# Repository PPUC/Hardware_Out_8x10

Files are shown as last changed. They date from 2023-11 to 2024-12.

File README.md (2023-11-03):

# Lamp Matrix PCB for PPUC Project
This is the hardware for a LED lamp matrix card which was designed for the PPUC pinball project, but can be useful in other applications as well. The intentionally usecase is to connect an original equipped pinball playfield (including cable harness). Normally I'd prefer a serial WS2812 LED strip to do a DIY pinball but if all the LEDs and cables are in place already, it is useful to connect the lamp matrix directly (for LED use only, not for incandescent bulbs as power of the outputs is limited).
It is designed for being low cost and functional for experimental use.  
Not everything is tested nor does it fulfill EMC or any other specifications.  
Use at your own risk!
To make use of anything of this project a basic understanding of electronics and programming is necessary. Nothing of it is "plug and play". I'm surely not liable for any damage to assemblies, pinball machines or even persons.

## Picture of the Board
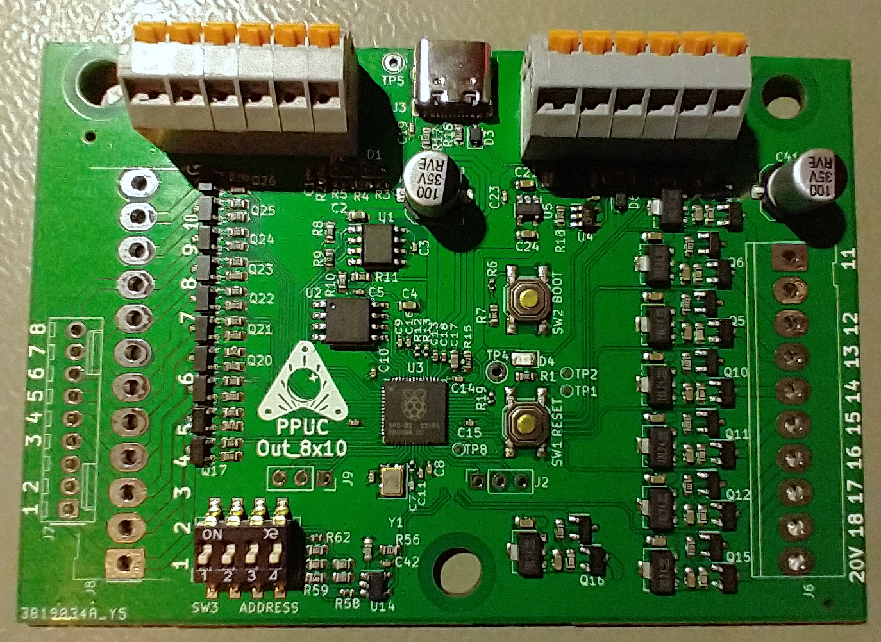
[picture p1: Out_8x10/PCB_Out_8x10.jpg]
PCB Pic


## Name
Out_8x10 as it has 18 outputs. 8 high side switches and 10 low side switches which can form a 8x10 matrix but could also be used as simple high side and low side outputs.  

## Power Supply
The IO card must be supplied by 5 V (+-0.5 V) for logic and nominal 20 V for outputs. As these outputs are open source and open drain, the 20 V supply can actually be 7 V up to 26 V. In the circuit diagram the voltage is called 20 V.

## Controller
A RP2040 is used for it's cost/performance ratio. It is the same controller that is used in the Raspberry Pi Pico.

## Communication Interfaces
* RS_485: main communication interface for controlling the outputs. Usually connected to a host interface like a PC or Raspberry Pi or similar.
* USB C: for programming, debug and flashing
* Serial Wire: alternative for programming, debug and flashing

## Switches (on board)
* Reset: hardware reset for controller (RP2040)
* Boot: if active, the board connects to a PC like an USB stick. Usually used for programming the code into the flash memory on the board.
* DIP-switches: usually used to select an address for RS485 (16 combinations)

## High Side Switch Outputs
There are 8 outputs featuring a high side switch, usually used for lamp coloums. The voltage is derived form 20 V power connection. Current and power is limited by a linear regulator (78L24) wich is actually not used for regulating the voltage but to protect the switch form overload in case of a short circuit. Each output can drive a constant current of 100 mA witch is normaly sufficiant for 10 LED lamps (e.g. 10 rows of LEDs). Short term peak current is about 300 mA. The 20 V supply can actually range from 7 V to 26 V (the lower limit is derived from UGS of the high side FET).

## Low Side Switch Outputs
There are 10 outputs featuring a low side switch, usually used for lamp rows. The outputs are open drain and drive currents up to 3 A with a load connected to a voltage of up to 30 V.

## Special Output
One special output is available for high speed signals. The voltage is 5 V, it is a push pull output that can drive a current up to 8 mA. It can be used to e.g. control a WS2812 LED strip.

## Connectors
There are pads for connectors that fit S.A.M. systems and also WPC systems. Be aware that J5 (WPC columns) is actually not in the PCB layout as it can be mounted on pins 1 to 9 of J6 (S.A.M. columns). The pinning is unfortunately vice versa so the connector of the original WPC cable harness has to be rotated by 180° (cables go to the inner side of PCB).

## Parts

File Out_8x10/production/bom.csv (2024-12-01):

Designator | Footprint | Quantity | Value | LCSC Part #
C1, C10, C11, C12, C14, C15, C16, C19, C20, C23, C3, C42, C5, C8, C9 | 0402 | 15 | 100n
C13, C18 | 0402 | 2 | 1u
C17, C2, C21, C24, C4 | 0603 | 5 | 10u
C22, C41 | CP_Elec_6.3x7.7 | 2 | 100µ 35V
C25, C26, C27, C28, C29, C30, C31, C32, C33, C34, C35, C36, C37, C38, C39, C40 | 0603 | 16 | 1u 50V
C6, C7 | 0402 | 2 | 27pF
D1, D2 | D_SOD-323 | 2 | SD15
D3, D7 | D_SOD-323 | 2 | 1A
D4 | 0805 | 1 | LED gn
D5 | D_SMA | 1 | SMAJ5.0
D6 | D_SOD-323 | 1 | SD05
J1, J4 | Terminal_Block_RTMPin | 2 | Conn_01x06
J3 | USB_C_Receptacle_XKB_U262-16XN-4BVC11 | 1 | USB_C_Receptacle_USB2.0
J6 | Molex_KK-396_5273-10A_1x10_P3.96mm_Vertical | 1 | Conn_01x10
J7 | Molex_KK-254_AE-6410-09A_1x09_P2.54mm_Vertical | 1 | Conn_01x09
J8 | Molex_KK-396_5273-12A_1x12_P3.96mm_Vertical | 1 | Conn_01x12
JP1 | PinHeader_1x02_P2.54mm_Vertical | 1 | Jumper_2_Open
Q1, Q13, Q14, Q2, Q3, Q7, Q8, Q9 | SOT-23 | 8 | 2N7002
Q10, Q11, Q12, Q15, Q16, Q4, Q5, Q6 | SOT-23 | 8 | AO3401A
Q17, Q18, Q19, Q20, Q21, Q22, Q23, Q24, Q25, Q26 | SOT-23 | 10 | AO3400A
R1, R10, R11, R18, R36, R37, R38, R39, R44, R45, R46, R47, R52, R53, R7, R8 | 0603 | 16 | 10k
R12, R13 | 0402 | 2 | 27
R14, R19, R58, R6, R62 | 0402 | 5 | 1k
R15, R2, R40, R41, R42, R43, R48, R49, R50, R51, R54, R55 | 0603 | 12 | 100R
R16, R17 | 0603 | 2 | 5k1
R20, R21, R22, R26, R27, R28, R32, R33, R57, R60, R61, R64 | 0603 | 12 | 2k
R23, R24, R25, R29, R30, R31, R34, R35 | 0603 | 8 | 3k3
R4 | 0603 | 1 | 120R
R56 | 0603 | 1 | 33k
R59 | 0603 | 1 | 5k
R63 | 0603 | 1 | 3k
R9 | 0603 | 1 | 0
SW1 | SW_SPST_SKQG_WithStem | 1 | Reset
SW2 | SW_SPST_SKQG_WithStem | 1 | Boot
SW3 | SW_DIP_SPSTx04_Slide_6.7x11.72mm_W8.61mm_P2.54mm_LowProfile | 1 | ADDRESS
TP1 | TestPoint_Pad_D1.0mm | 1 | TP_IO26
TP2 | TestPoint_Pad_D1.0mm | 1 | TP_IO27
U1 | SOIC-8_3.9x4.9mm_P1.27mm | 1 | ADM3483
U10, U11, U12, U13, U6, U7, U8, U9 | SOT-89-3 | 8 | L78L24_SOT89
U14 | SOT-23-5 | 1 | LMV321
U2 | SOIC-8_5.23x5.23mm_P1.27mm | 1 | W25Q128JVSIQ
U3 | QFN-56-1EP_7x7mm_P0.4mm_EP3.2x3.2mm | 1 | RP2040
U4 | SOT-23-5 | 1 | SN74AHCT1G125
U5 | SOT-23-5 | 1 | AP2112K-3.3
Y1 | Crystal_SMD_3225-4Pin_3.2x2.5mm | 1 | 12MHz,18pF

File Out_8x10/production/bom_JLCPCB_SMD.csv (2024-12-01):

Designator | Footprint | Quantity | Value | LCSC Part #
C1, C10, C11, C12, C14, C15, C16, C19, C20, C23, C3, C42, C5, C8, C9 | 0402 | 15 | 100n | C1525
C13, C18 | 0402 | 2 | 1u | C52923
C17, C2, C21, C24, C4 | 0603 | 5 | 10u | C19702
C22, C41 | CP_Elec_6.3x7.7 | 2 | 100µ 35V | C2836437
C25, C26, C27, C28, C29, C30, C31, C32, C33, C34, C35, C36, C37, C38, C39, C40 | 0603 | 16 | 1u 50V | C15849
C6, C7 | 0402 | 2 | 27pF | C1557
D1, D2 | D_SOD-323 | 2 | SD15 | C502529
D3, D7 | D_SOD-323 | 2 | 1A | C191023
D4 | 0805 | 1 | LED gn | C2297
D5 | D_SMA | 1 | SMAJ5.0 | C2925443
D6 | D_SOD-323 | 1 | SD05 | C2972756
J3 | USB_C_Receptacle_XKB_U262-16XN-4BVC11 | 1 | USB_C_Receptacle_USB2.0 | C709357
Q1, Q13, Q14, Q2, Q3, Q7, Q8, Q9 | SOT-23 | 8 | 2N7002 | C8545
Q10, Q11, Q12, Q15, Q16, Q4, Q5, Q6 | SOT-23 | 8 | AO3401A | C15127
Q17, Q18, Q19, Q20, Q21, Q22, Q23, Q24, Q25, Q26 | SOT-23 | 10 | AO3400A | C20917
R1, R10, R11, R18, R36, R37, R38, R39, R44, R45, R46, R47, R52, R53, R7, R8 | 0603 | 16 | 10k | C25804
R12, R13 | 0402 | 2 | 27 | C138021
R14, R19, R58, R6, R62 | 0402 | 5 | 1k | C11702
R15, R2, R40, R41, R42, R43, R48, R49, R50, R51, R54, R55 | 0603 | 12 | 100R | C22775
R16, R17 | 0603 | 2 | 5k1 | C23186
R20, R21, R22, R26, R27, R28, R32, R33, R57, R60, R61, R64 | 0603 | 12 | 2k | C22975
R23, R24, R25, R29, R30, R31, R34, R35 | 0603 | 8 | 3k3 | C22978
R4 | 0603 | 1 | 120R | C22787
R56 | 0603 | 1 | 33k | C4216
R59 | 0603 | 1 | 5k | C101077
R63 | 0603 | 1 | 3k | C4211
R9 | 0603 | 1 | 0 | C21189
SW1 | SW_SPST_SKQG_WithStem | 1 | Reset | C318884
SW2 | SW_SPST_SKQG_WithStem | 1 | Boot | C318884
SW3 | SW_DIP_SPSTx04_Slide_6.7x11.72mm_W8.61mm_P2.54mm_LowProfile | 1 | ADDRESS | C54950
U1 | SOIC-8_3.9x4.9mm_P1.27mm | 1 | ADM3483 | C609792
U10, U11, U12, U13, U6, U7, U8, U9 | SOT-89-3 | 8 | L78L24_SOT89 | C5309539
U14 | SOT-23-5 | 1 | LMV321 | C7972
U2 | SOIC-8_5.23x5.23mm_P1.27mm | 1 | W25Q128JVSIQ | C97521
U3 | QFN-56-1EP_7x7mm_P0.4mm_EP3.2x3.2mm | 1 | RP2040 | C2040
U4 | SOT-23-5 | 1 | SN74AHCT1G125 | C7484
U5 | SOT-23-5 | 1 | AP2112K-3.3 | C51118
Y1 | Crystal_SMD_3225-4Pin_3.2x2.5mm | 1 | 12MHz,18pF | C9002

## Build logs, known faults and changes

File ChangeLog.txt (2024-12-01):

2024-12-01  foenich

	Released Version 1.0.0
	Jumper for RS485 termination. Removed bias resistors.
	Prevented current from USB to 5V_IN.
	More terminals for A and B.
	
	* removed F1 (as +5V is no loger at a terminal)
	* inserted D7
	* changed J1, pin 4 from GND to A and pin 5 from GND to B
	* inserted JP1
	* removed R3 and R5

2023-10-22  foenich

	Released Version 0.2.0
	TP as RM2.54 terminal
	
	* changed 3 TPs to RM2.54 terminal
	* changed versioning to x.y.z (major.functional change.bugfix)

2023-10-20  foenich

	Released Version 00.20
	read DIP switch analog (SW compatible to IO_16_8_1)
	
	* added anlog circuit and changed wiring to uC

2023-10-08  foenich

	Released initial Version 0.10

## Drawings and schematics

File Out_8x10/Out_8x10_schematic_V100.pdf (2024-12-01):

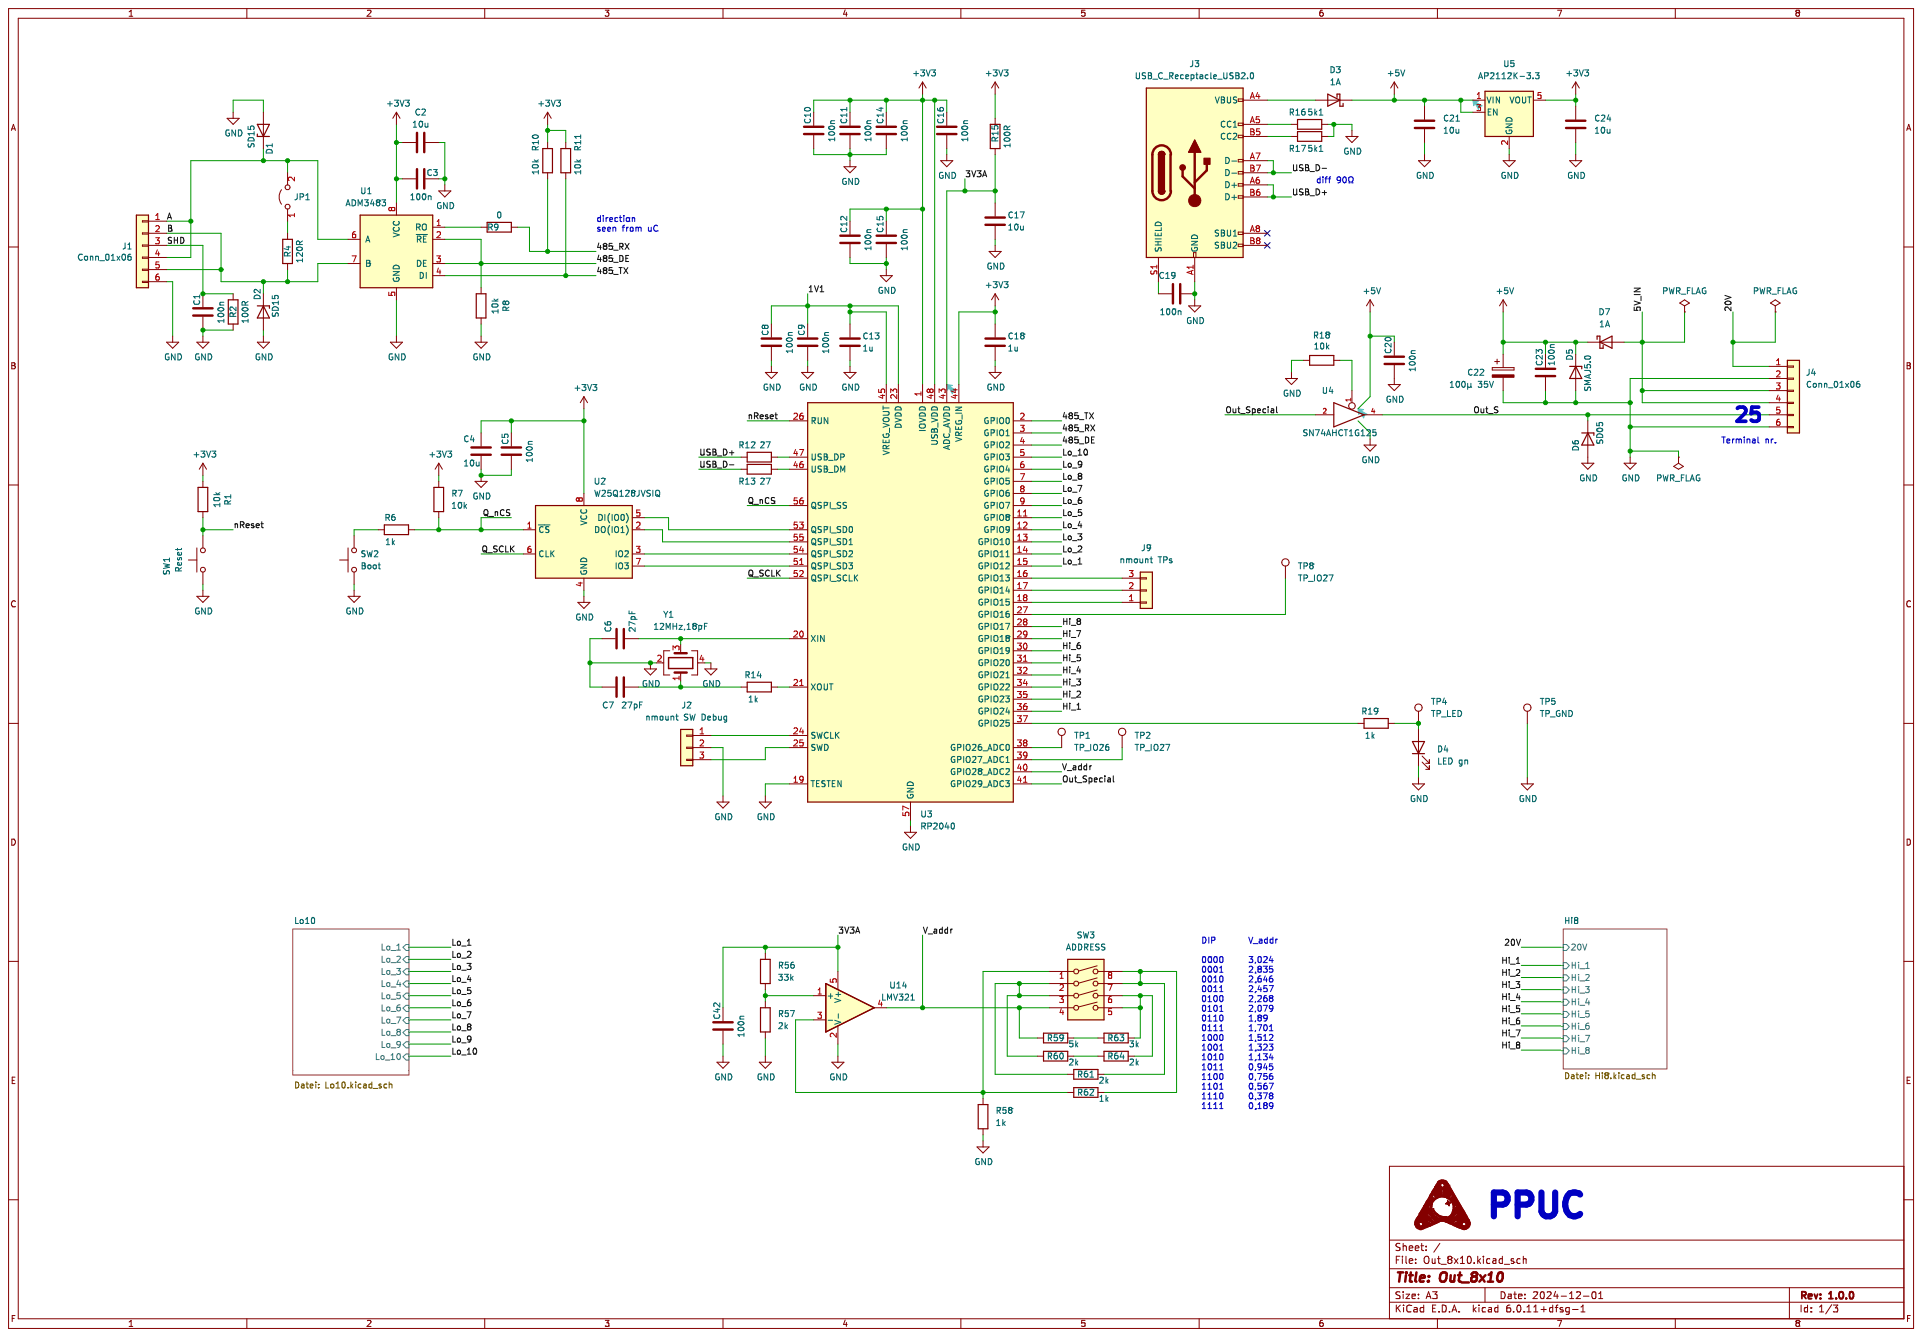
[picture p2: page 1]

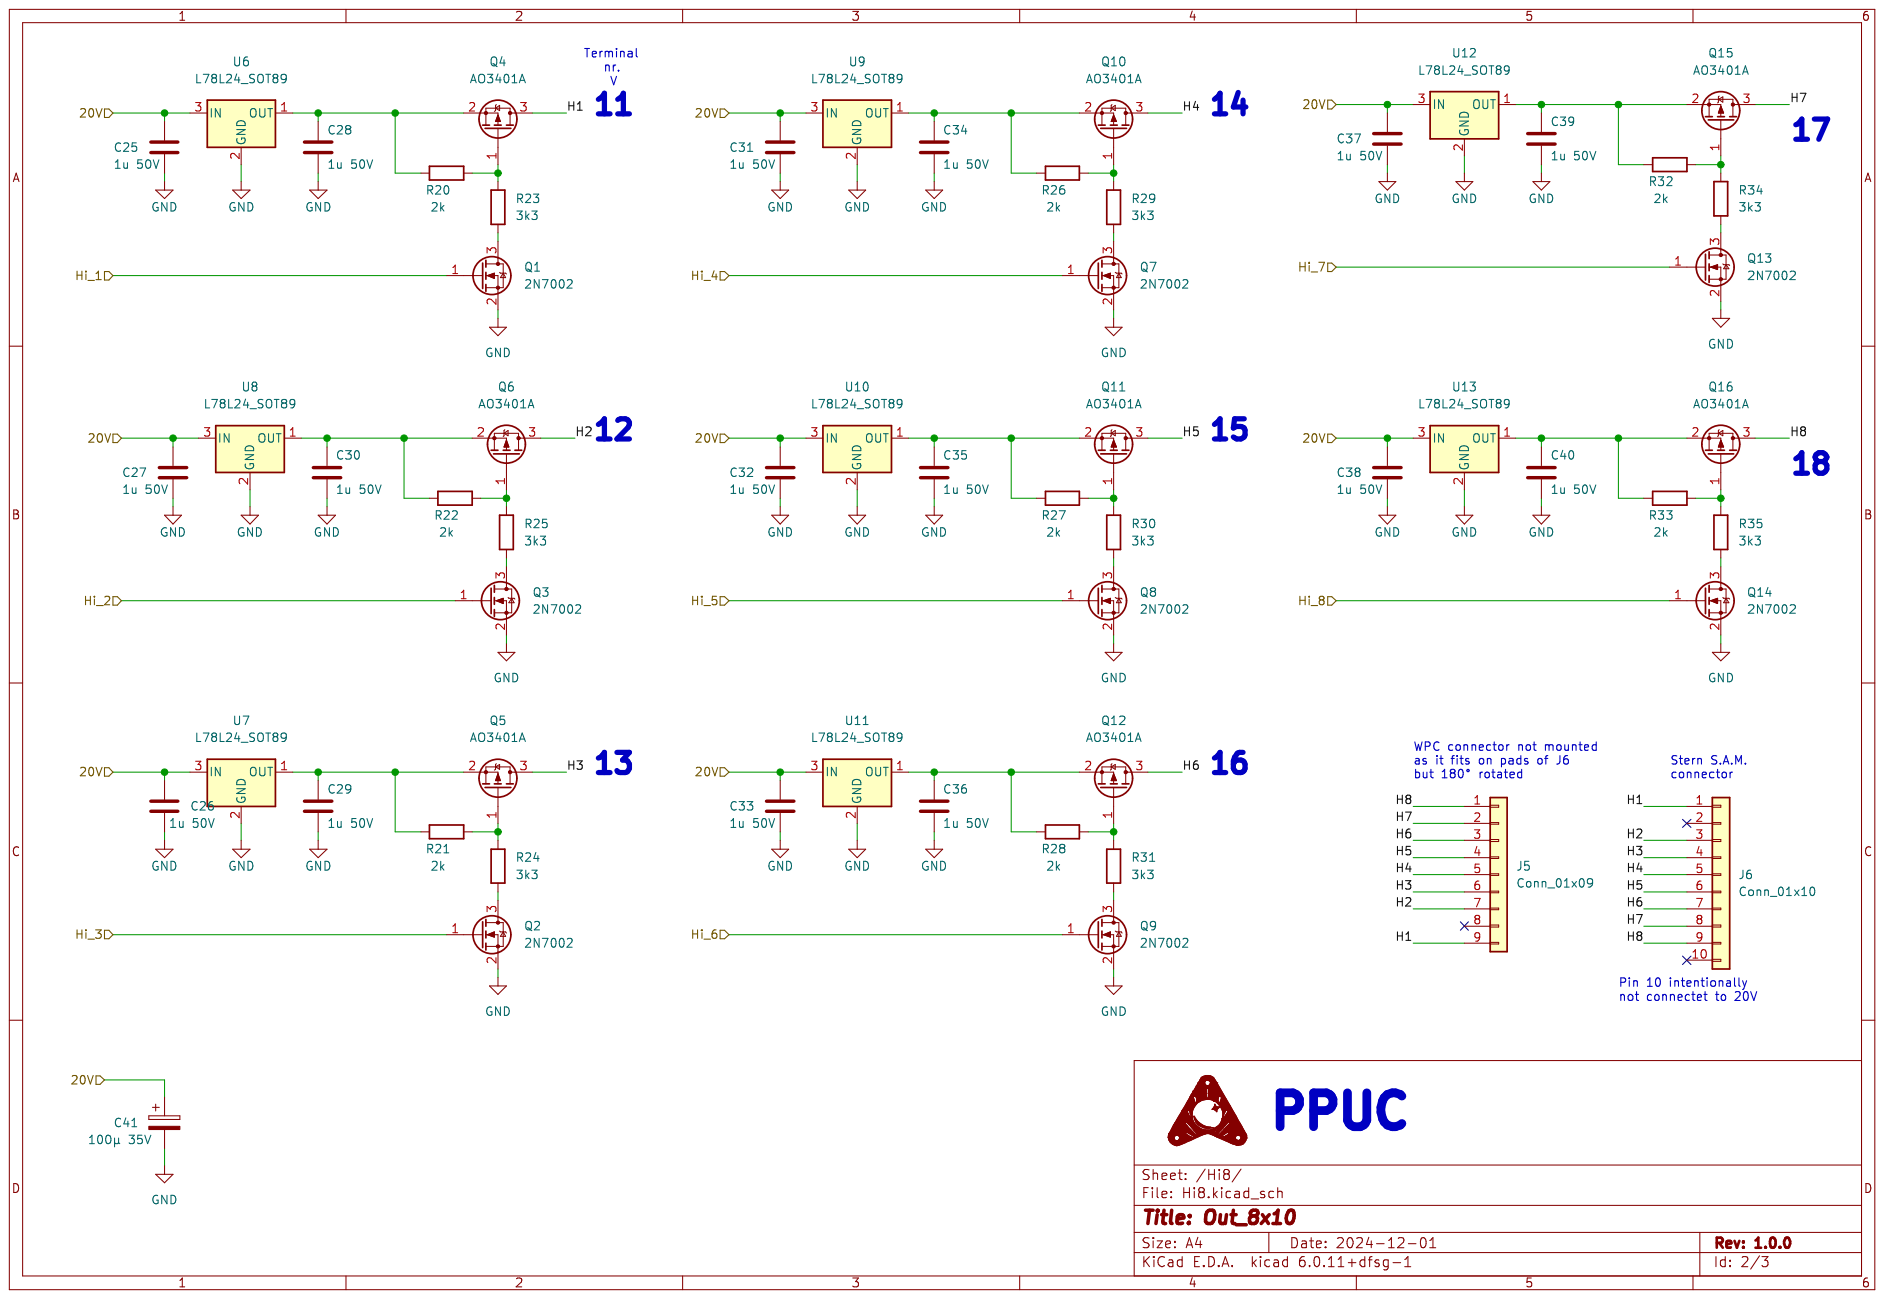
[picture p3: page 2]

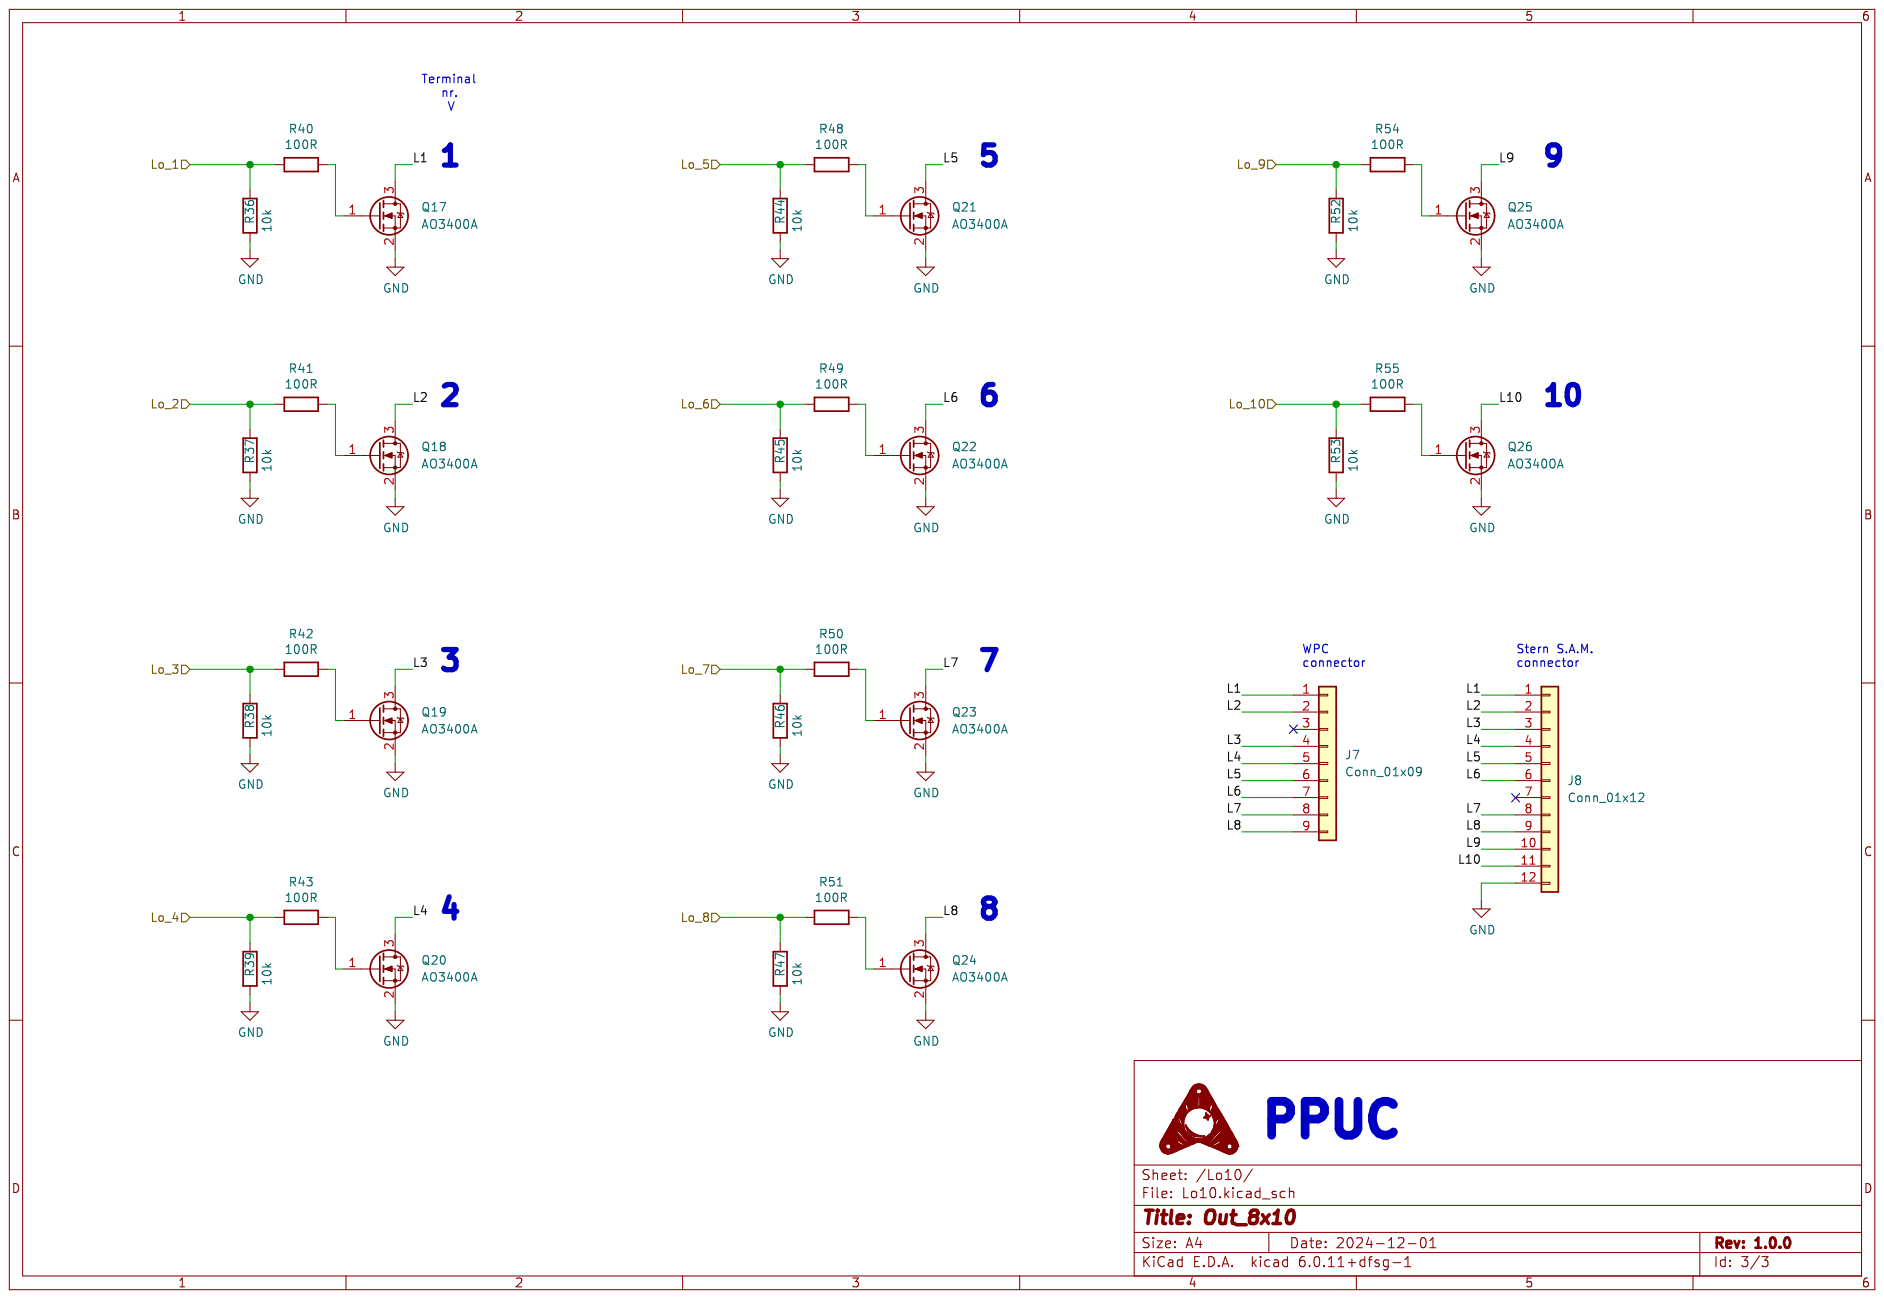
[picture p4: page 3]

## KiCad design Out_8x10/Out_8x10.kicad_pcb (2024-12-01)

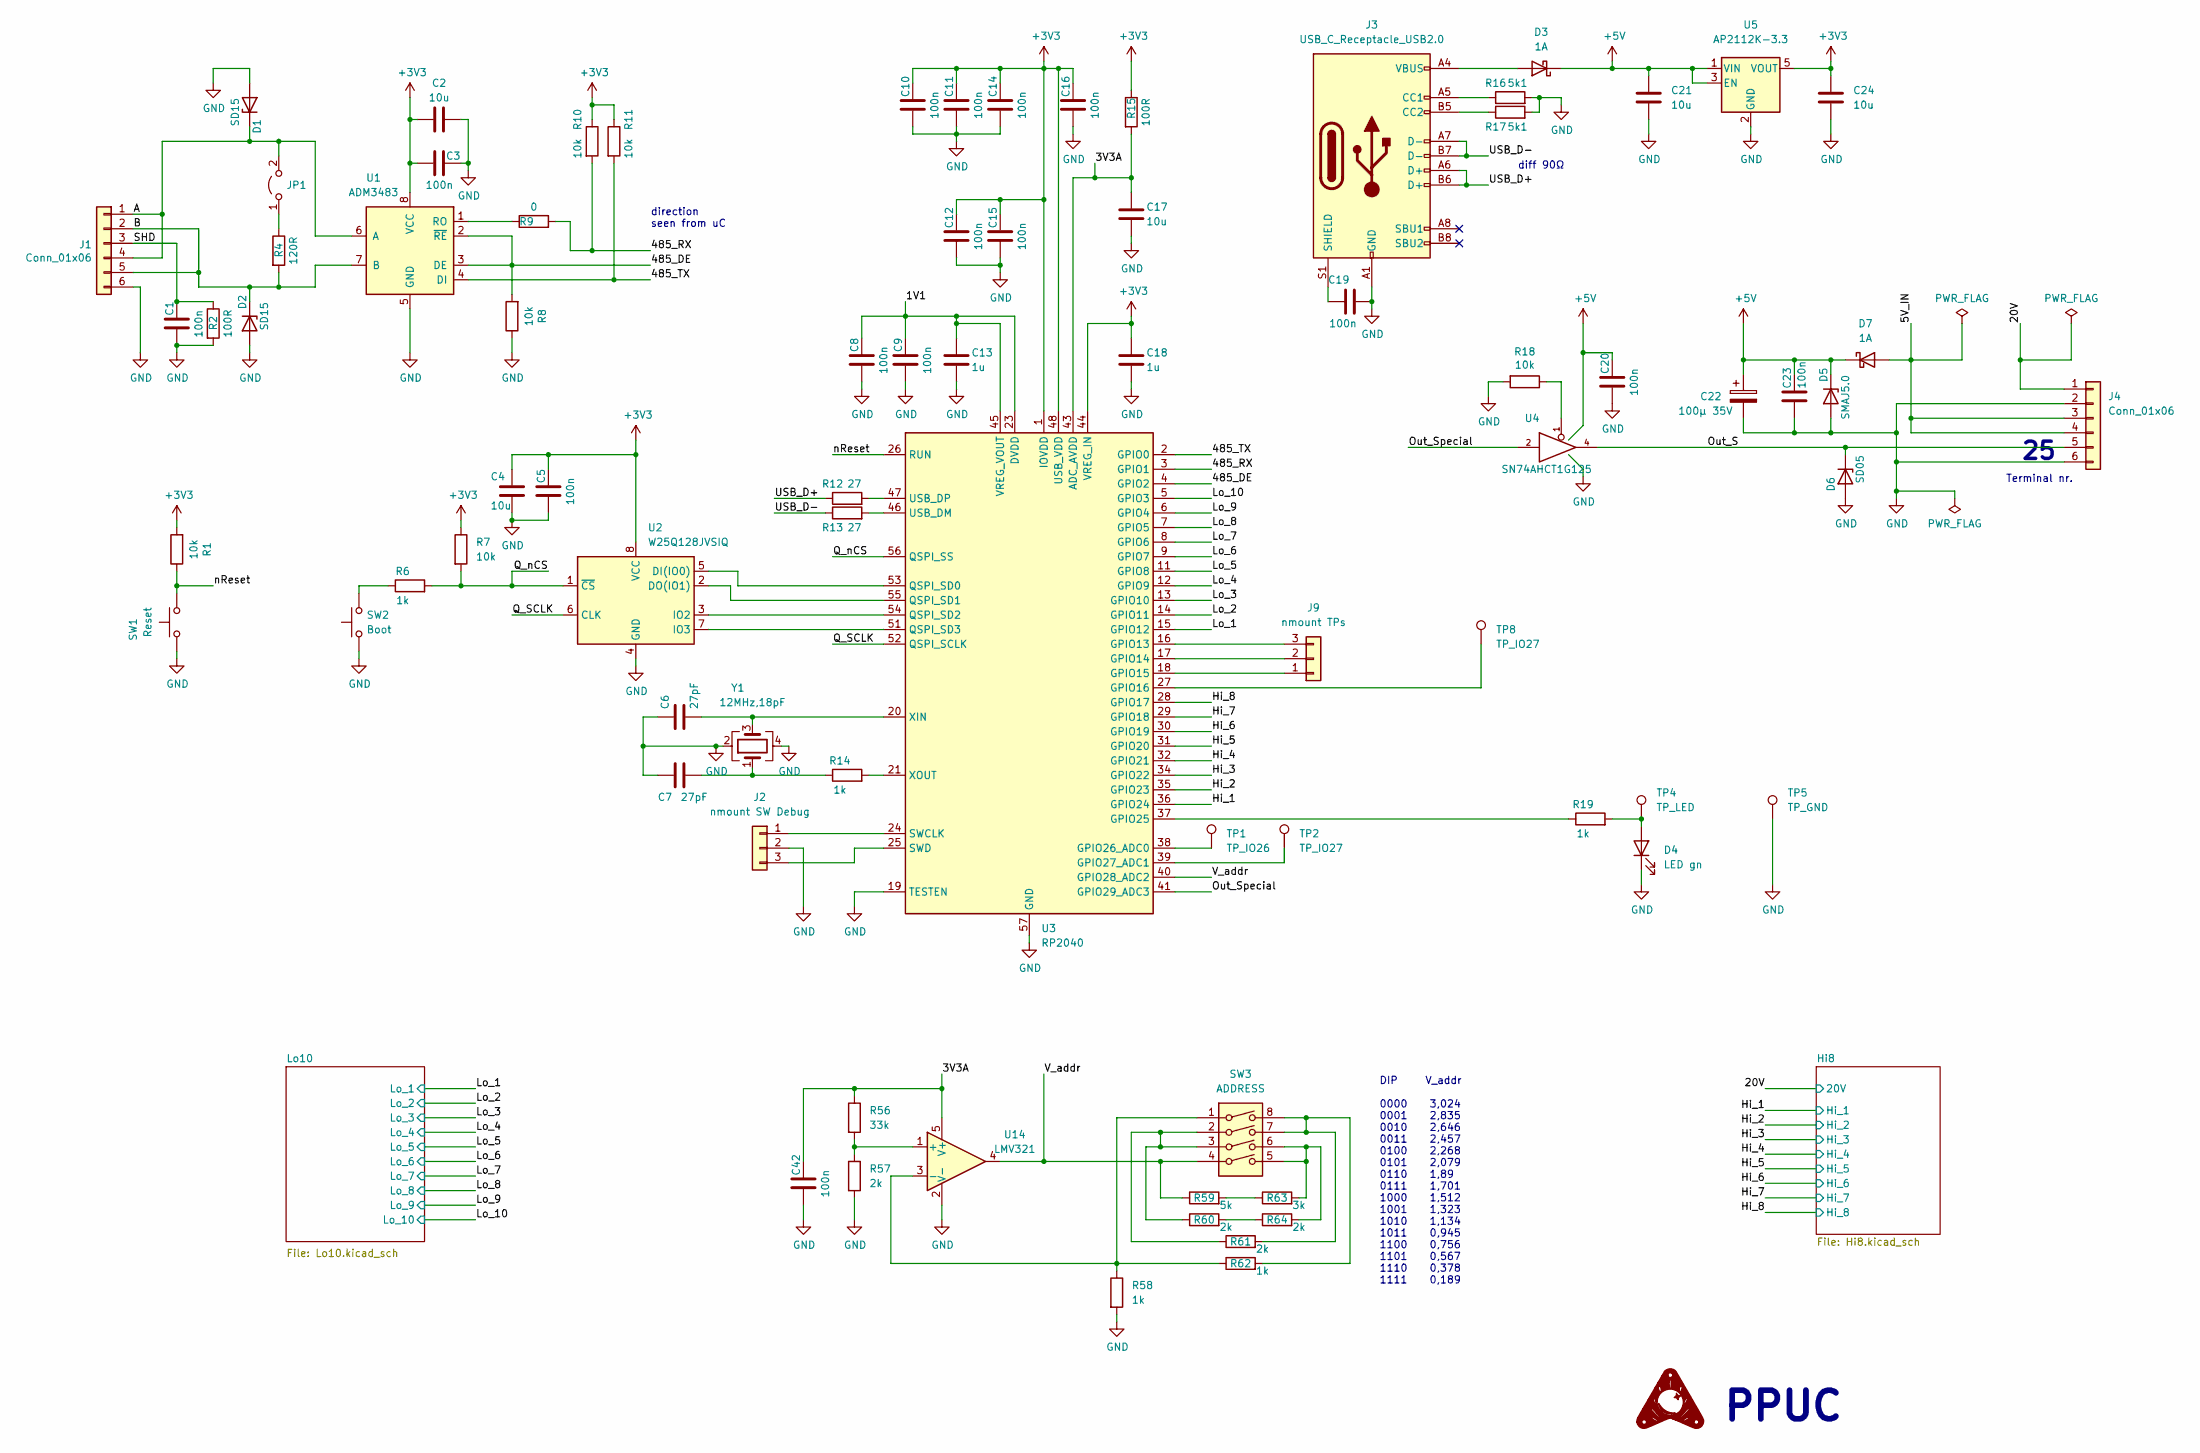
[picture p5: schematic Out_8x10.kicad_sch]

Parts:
C1, C3, C5, C8, C9, C10, C11, C12, C14, C15, C16, C19, C20, C23, C42: 100n; C_0402_1005Metric
C2, C4, C17, C21, C24: 10u; C_0603_1608Metric
C6, C7: 27pF; C_0402_1005Metric
C13, C18: 1u; C_0402_1005Metric
C22: 100µ 35V; CP_Elec_6.3x7.7; JLCPCB Rotation Offset 180
D1, D2: SD15; D_SOD-323
D3, D7: 1A; D_SOD-323
D4: LED gn; LED_0805_2012Metric
D5: SMAJ5.0; D_SMA
D6: SD05; D_SOD-323
J1, J4: Conn_01x06; Terminal_Block_RTMPin
J2: nmount SW Debug; PinSocket_1x03_P2.54mm_Vertical
J3: USB_C_Receptacle_USB2.0; USB_C_Receptacle_XKB_U262-16XN-4BVC11
J9: nmount TPs; PinSocket_1x03_P2.54mm_Vertical
JP1: Jumper_2_Open; PinHeader_1x02_P2.54mm_Vertical
R1, R7, R8, R10, R11, R18: 10k; R_0603_1608Metric
R2, R15: 100R; R_0603_1608Metric
R4: 120R; R_0603_1608Metric
R6, R14, R19, R58, R62: 1k; R_0402_1005Metric
R9: 0; R_0603_1608Metric
R12, R13: 27; R_0402_1005Metric
R16, R17: 5k1; R_0603_1608Metric
R56: 33k; R_0603_1608Metric
R57, R60, R61, R64: 2k; R_0603_1608Metric
R59: 5k; R_0603_1608Metric
R63: 3k; R_0603_1608Metric
SW1: Reset; SW_SPST_SKQG_WithStem
SW2: Boot; SW_SPST_SKQG_WithStem
SW3: ADDRESS; SW_DIP_SPSTx04_Slide_6.7x11.72mm_W8.61mm_P2.54mm_LowProfile; JLCPCB Rotation Offset 90
TP1: TP_IO26; TestPoint_Pad_D1.0mm
TP2, TP8: TP_IO27; TestPoint_Pad_D1.0mm
TP4: TP_LED; Pin_D1.0mm_L10.0mm
TP5: TP_GND; Pin_D1.0mm_L10.0mm
U1: ADM3483; SOIC-8_3.9x4.9mm_P1.27mm
U2: W25Q128JVSIQ; SOIC-8_5.23x5.23mm_P1.27mm
U3: RP2040; QFN-56-1EP_7x7mm_P0.4mm_EP3.2x3.2mm; JLCPCB Rotation Offset -90
U4: SN74AHCT1G125; SOT-23-5
U5: AP2112K-3.3; SOT-23-5; JLCPCB Rotation Offset 90
U14: LMV321; SOT-23-5
Y1: 12MHz,18pF; Crystal_SMD_3225-4Pin_3.2x2.5mm

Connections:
+3V3: C2.1, C3.1, C4.1, C5.1, C10.1, C11.1, C12.1, C14.1, C15.1, C16.1, C18.1, C24.1, R1.2, R7.1, R10.1, R11.1, R15.1, U1.8 (VCC), U2.8 (VCC), U3.1 (IOVDD), U3.10 (IOVDD), U3.22 (IOVDD), U3.33 (IOVDD), U3.42 (IOVDD), U3.44 (VREG_IN), U3.48 (USB_VDD), U3.49 (IOVDD), U5.5 (VOUT)
+5V: C20.1, C21.1, C22.1, C23.1, D3.1 (K), D5.1 (K), D7.1 (K), U4.5 (VCC), U5.1 (VIN), U5.3 (EN)
/1V1: C8.1, C9.1, C13.1, U3.23 (DVDD), U3.45 (VREG_VOUT), U3.50 (DVDD)
/3V3A: C17.1, C42.1, R15.2, R56.1, U3.43 (ADC_AVDD), U14.5 (V+)
/485_DE: R8.2, U1.2 (~RE), U1.3 (DE), U3.4 (GPIO2)
/485_RX: R9.2, R10.2, U3.3 (GPIO1)
/485_TX: R11.2, U1.4 (DI), U3.2 (GPIO0)
/A: D1.1 (K), J1.1, J1.4, JP1.2 (B), U1.6 (A)
/B: D2.1 (K), J1.2, J1.5, R4.2, U1.7 (B)
/Hi_1: U3.36 (GPIO24); also elsewhere on the board
/Hi_2: U3.35 (GPIO23); also elsewhere on the board
/Hi_3: U3.34 (GPIO22); also elsewhere on the board
/Hi_4: U3.32 (GPIO21); also elsewhere on the board
/Hi_5: U3.31 (GPIO20); also elsewhere on the board
/Hi_6: U3.30 (GPIO19); also elsewhere on the board
/Hi_7: U3.29 (GPIO18); also elsewhere on the board
/Hi_8: U3.28 (GPIO17); also elsewhere on the board
/Lo_1: U3.15 (GPIO12); also elsewhere on the board
/Lo_2: U3.14 (GPIO11); also elsewhere on the board
/Lo_3: U3.13 (GPIO10); also elsewhere on the board
/Lo_4: U3.12 (GPIO9); also elsewhere on the board
/Lo_5: U3.11 (GPIO8); also elsewhere on the board
/Lo_6: U3.9 (GPIO7); also elsewhere on the board
/Lo_7: U3.8 (GPIO6); also elsewhere on the board
/Lo_8: U3.7 (GPIO5); also elsewhere on the board
/Lo_9: U3.6 (GPIO4); also elsewhere on the board
/Lo_10: U3.5 (GPIO3); also elsewhere on the board
/Out_S: D6.1 (K), J4.5, U4.4
/Out_Special: U3.41 (GPIO29_ADC3), U4.2
/Q_SCLK: U2.6 (CLK), U3.52 (QSPI_SCLK)
/Q_nCS: R6.2, R7.2, U2.1 (~CS), U3.56 (QSPI_SS)
/SHD: C1.1, J1.3, R2.1
/USB_D+: J3.A6 (D+), J3.B6 (D+), R12.1
/USB_D-: J3.A7 (D-), J3.B7 (D-), R13.1
/V_addr: R59.1, SW3.4, U3.40 (GPIO28_ADC2), U14.4
/nReset: R1.1, SW1.2, U3.26 (RUN)
unnamed: C6.2, U3.20 (XIN), Y1.3
unnamed: C7.2, R14.1, Y1.1
unnamed: C19.1, J3.S1 (SHIELD)
unnamed: D3.2 (A), J3.A4 (VBUS), J3.A9 (VBUS), J3.B4 (VBUS), J3.B9 (VBUS)
unnamed: D4.2 (A), R19.2, TP4.1
unnamed: J2.1, U3.24 (SWCLK)
unnamed: J2.3, U3.25 (SWD)
unnamed: J3.A5 (CC1), R16.1
unnamed: J3.B5 (CC2), R17.1
unnamed: J9.1, U3.18 (GPIO15)
unnamed: J9.2, U3.17 (GPIO14)
unnamed: J9.3, U3.16 (GPIO13)
unnamed: JP1.1 (A), R4.1
unnamed: R6.1, SW2.2
unnamed: R9.1, U1.1 (RO)
unnamed: R12.2, U3.47 (USB_DP)
unnamed: R13.2, U3.46 (USB_DM)
unnamed: R14.2, U3.21 (XOUT)
unnamed: R18.1, U4.1
unnamed: R19.1, U3.37 (GPIO25)
unnamed: R56.2, R57.1, U14.1 (+)
unnamed: R58.1, R62.1, SW3.1, U14.3 (-)
unnamed: R59.2, R63.1
unnamed: R60.1, R61.1, SW3.2, SW3.3
unnamed: R60.2, R64.1
unnamed: R61.2, R62.2, SW3.7, SW3.8
unnamed: R63.2, R64.2, SW3.5, SW3.6
unnamed: TP1.1, U3.38 (GPIO26_ADC0)
unnamed: TP2.1, U3.39 (GPIO27_ADC1)
unnamed: TP8.1, U3.27 (GPIO16)
unnamed: U2.2 (DO(IO1)), U3.55 (QSPI_SD1)
unnamed: U2.3 (IO2), U3.54 (QSPI_SD2)
unnamed: U2.5 (DI(IO0)), U3.53 (QSPI_SD0)
unnamed: U2.7 (IO3), U3.51 (QSPI_SD3)

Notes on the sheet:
DIP V_addr 0000 3,024 0001 2,835 0010 2,646 0011 2,457 0100 2,268 0101 2,079 0110 1,89 0111 1,701 1000 1,512 1001 1,323 1010 1,134 1011 0,945 1100 0,756 1101 0,567 1110 0,378 1111 0,189
diff 90Ω
Terminal nr.
direction seen from uC
PPUC

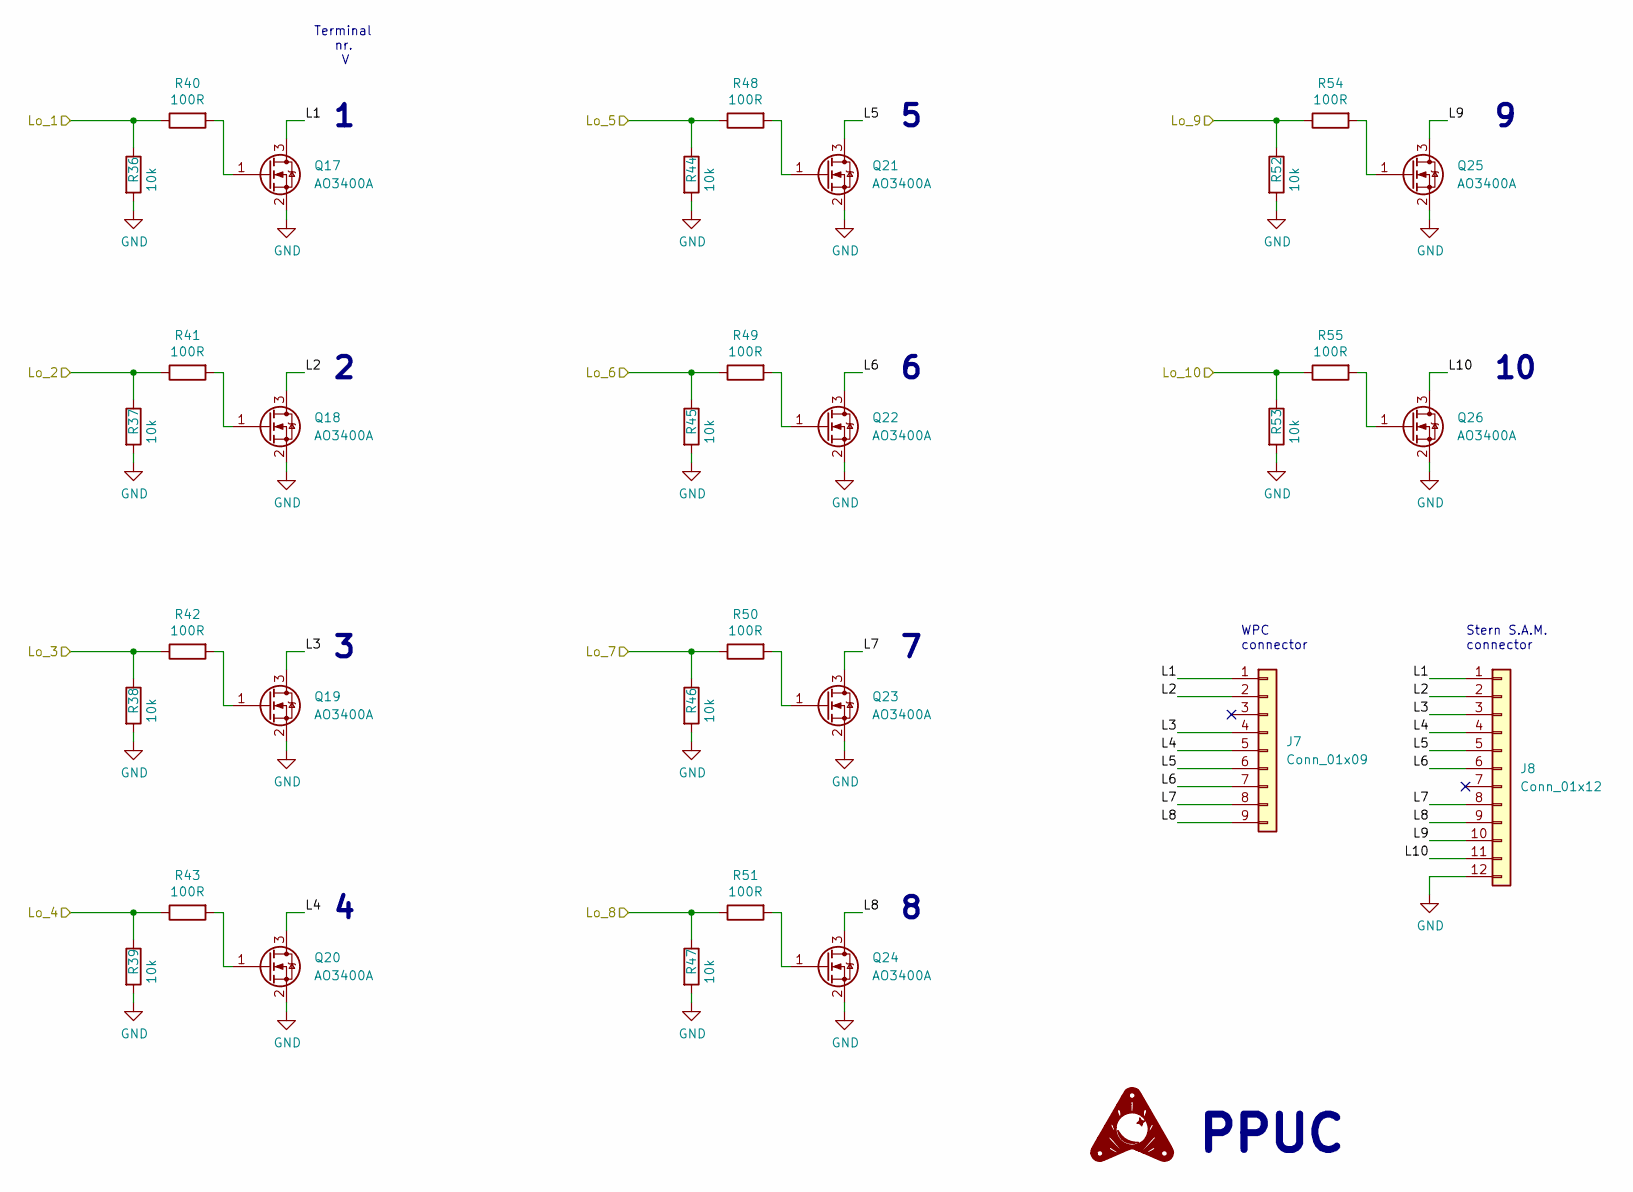
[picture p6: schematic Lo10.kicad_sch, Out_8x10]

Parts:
J7: Conn_01x09; Molex_KK-254_AE-6410-09A_1x09_P2.54mm_Vertical
J8: Conn_01x12; Molex_KK-396_5273-12A_1x12_P3.96mm_Vertical
Q17, Q18, Q19, Q20, Q21, Q22, Q23, Q24, Q25, Q26: AO3400A; SOT-23
R36, R37, R38, R39, R44, R45, R46, R47, R52, R53: 10k; R_0603_1608Metric
R40, R41, R42, R43, R48, R49, R50, R51, R54, R55: 100R; R_0603_1608Metric

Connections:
/Lo10/L1: J7.1, J8.1, Q17.3 (D)
/Lo10/L2: J7.2, J8.2, Q18.3 (D)
/Lo10/L3: J7.4, J8.3, Q19.3 (D)
/Lo10/L4: J7.5, J8.4, Q20.3 (D)
/Lo10/L5: J7.6, J8.5, Q21.3 (D)
/Lo10/L6: J7.7, J8.6, Q22.3 (D)
/Lo10/L7: J7.8, J8.8, Q23.3 (D)
/Lo10/L8: J7.9, J8.9, Q24.3 (D)
/Lo10/L9: J8.10, Q25.3 (D)
/Lo10/L10: J8.11, Q26.3 (D)
/Lo_1: R36.1, R40.1; also elsewhere on the board
/Lo_2: R37.1, R41.1; also elsewhere on the board
/Lo_3: R38.1, R42.1; also elsewhere on the board
/Lo_4: R39.1, R43.1; also elsewhere on the board
/Lo_5: R44.1, R48.1; also elsewhere on the board
/Lo_6: R45.1, R49.1; also elsewhere on the board
/Lo_7: R46.1, R50.1; also elsewhere on the board
/Lo_8: R47.1, R51.1; also elsewhere on the board
/Lo_9: R52.1, R54.1; also elsewhere on the board
/Lo_10: R53.1, R55.1; also elsewhere on the board
unnamed: Q17.1 (G), R40.2
unnamed: Q18.1 (G), R41.2
unnamed: Q19.1 (G), R42.2
unnamed: Q20.1 (G), R43.2
unnamed: Q21.1 (G), R48.2
unnamed: Q22.1 (G), R49.2
unnamed: Q23.1 (G), R50.2
unnamed: Q24.1 (G), R51.2
unnamed: Q25.1 (G), R54.2
unnamed: Q26.1 (G), R55.2

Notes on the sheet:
PPUC
WPC connector
Terminal nr. V
Stern S.A.M. connector

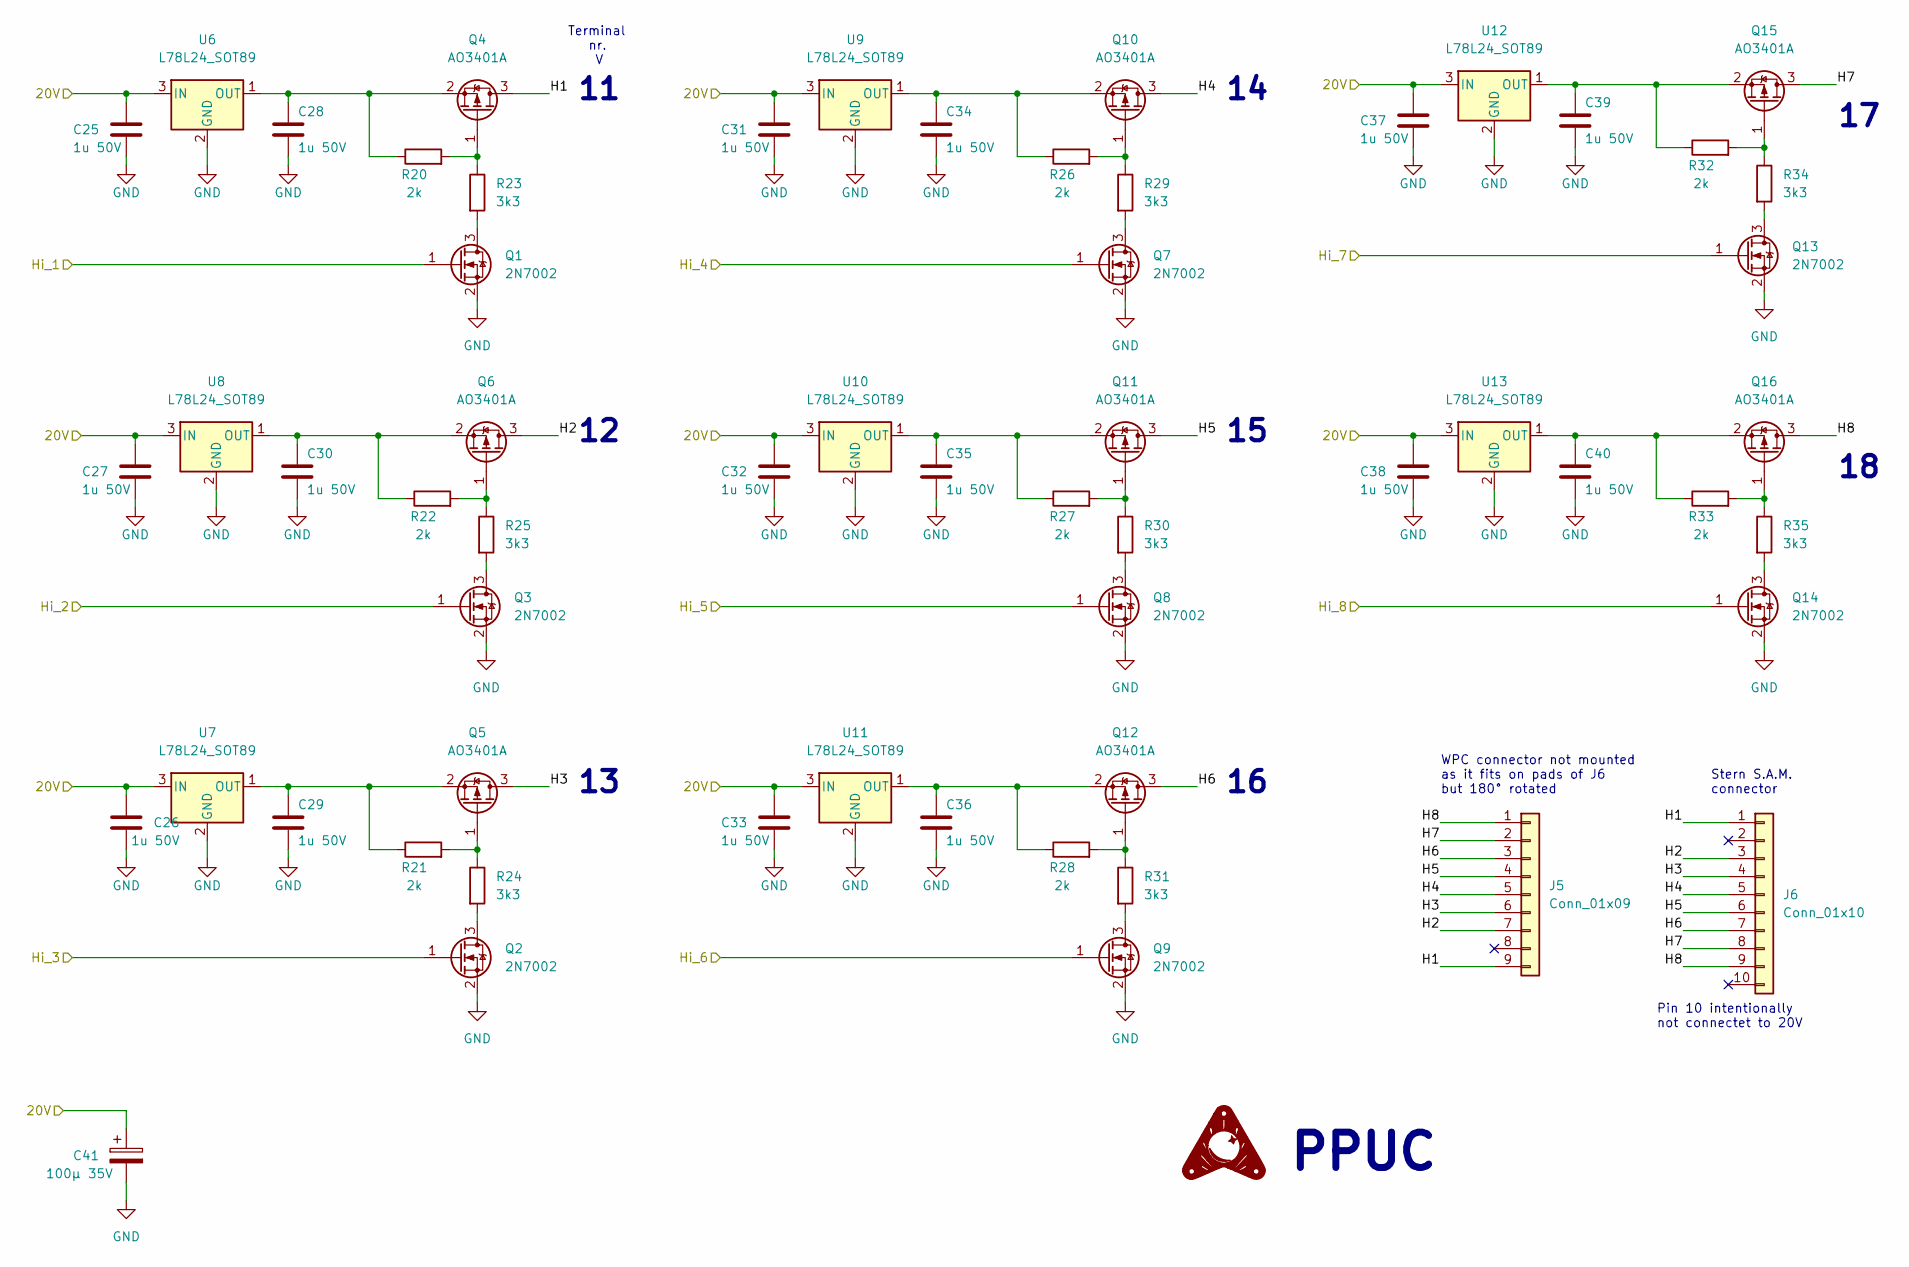
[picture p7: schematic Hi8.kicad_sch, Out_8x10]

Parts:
C25, C26, C27, C28, C29, C30, C31, C32, C33, C34, C35, C36, C37, C38, C39, C40: 1u 50V; C_0603_1608Metric
C41: 100µ 35V; CP_Elec_6.3x7.7; JLCPCB Rotation Offset 180
J5: Conn_01x09; Molex_KK-396_5273-09A_1x09_P3.96mm_Vertical
J6: Conn_01x10; Molex_KK-396_5273-10A_1x10_P3.96mm_Vertical
Q1, Q2, Q3, Q7, Q8, Q9, Q13, Q14: 2N7002; SOT-23
Q4, Q5, Q6, Q10, Q11, Q12, Q15, Q16: AO3401A; SOT-23
R20, R21, R22, R26, R27, R28, R32, R33: 2k; R_0603_1608Metric
R23, R24, R25, R29, R30, R31, R34, R35: 3k3; R_0603_1608Metric
U6, U7, U8, U9, U10, U11, U12, U13: L78L24_SOT89; SOT-89-3

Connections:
/Hi8/H1: J5.9, J6.1, Q4.3 (D)
/Hi8/H2: J5.7, J6.3, Q6.3 (D)
/Hi8/H3: J5.6, J6.4, Q5.3 (D)
/Hi8/H4: J5.5, J6.5, Q10.3 (D)
/Hi8/H5: J5.4, J6.6, Q11.3 (D)
/Hi8/H6: J5.3, J6.7, Q12.3 (D)
/Hi8/H7: J5.2, J6.8, Q15.3 (D)
/Hi8/H8: J5.1, J6.9, Q16.3 (D)
/Hi_1: Q1.1 (G); also elsewhere on the board
/Hi_2: Q3.1 (G); also elsewhere on the board
/Hi_3: Q2.1 (G); also elsewhere on the board
/Hi_4: Q7.1 (G); also elsewhere on the board
/Hi_5: Q8.1 (G); also elsewhere on the board
/Hi_6: Q9.1 (G); also elsewhere on the board
/Hi_7: Q13.1 (G); also elsewhere on the board
/Hi_8: Q14.1 (G); also elsewhere on the board
unnamed: C28.1, Q4.2 (S), R20.1, U6.1 (OUT)
unnamed: C29.1, Q5.2 (S), R21.1, U7.1 (OUT)
unnamed: C30.1, Q6.2 (S), R22.1, U8.1 (OUT)
unnamed: C34.1, Q10.2 (S), R26.1, U9.1 (OUT)
unnamed: C35.1, Q11.2 (S), R27.1, U10.1 (OUT)
unnamed: C36.1, Q12.2 (S), R28.1, U11.1 (OUT)
unnamed: C39.1, Q15.2 (S), R32.1, U12.1 (OUT)
unnamed: C40.1, Q16.2 (S), R33.1, U13.1 (OUT)
unnamed: Q1.3 (D), R23.2
unnamed: Q2.3 (D), R24.2
unnamed: Q3.3 (D), R25.2
unnamed: Q4.1 (G), R20.2, R23.1
unnamed: Q5.1 (G), R21.2, R24.1
unnamed: Q6.1 (G), R22.2, R25.1
unnamed: Q7.3 (D), R29.2
unnamed: Q8.3 (D), R30.2
unnamed: Q9.3 (D), R31.2
unnamed: Q10.1 (G), R26.2, R29.1
unnamed: Q11.1 (G), R27.2, R30.1
unnamed: Q12.1 (G), R28.2, R31.1
unnamed: Q13.3 (D), R34.2
unnamed: Q14.3 (D), R35.2
unnamed: Q15.1 (G), R32.2, R34.1
unnamed: Q16.1 (G), R33.2, R35.1

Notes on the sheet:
PPUC
Terminal nr. V
Stern S.A.M. connector
Pin 10 intentionally not connectet to 20V
WPC connector not mounted as it fits on pads of J6 but 180° rotated

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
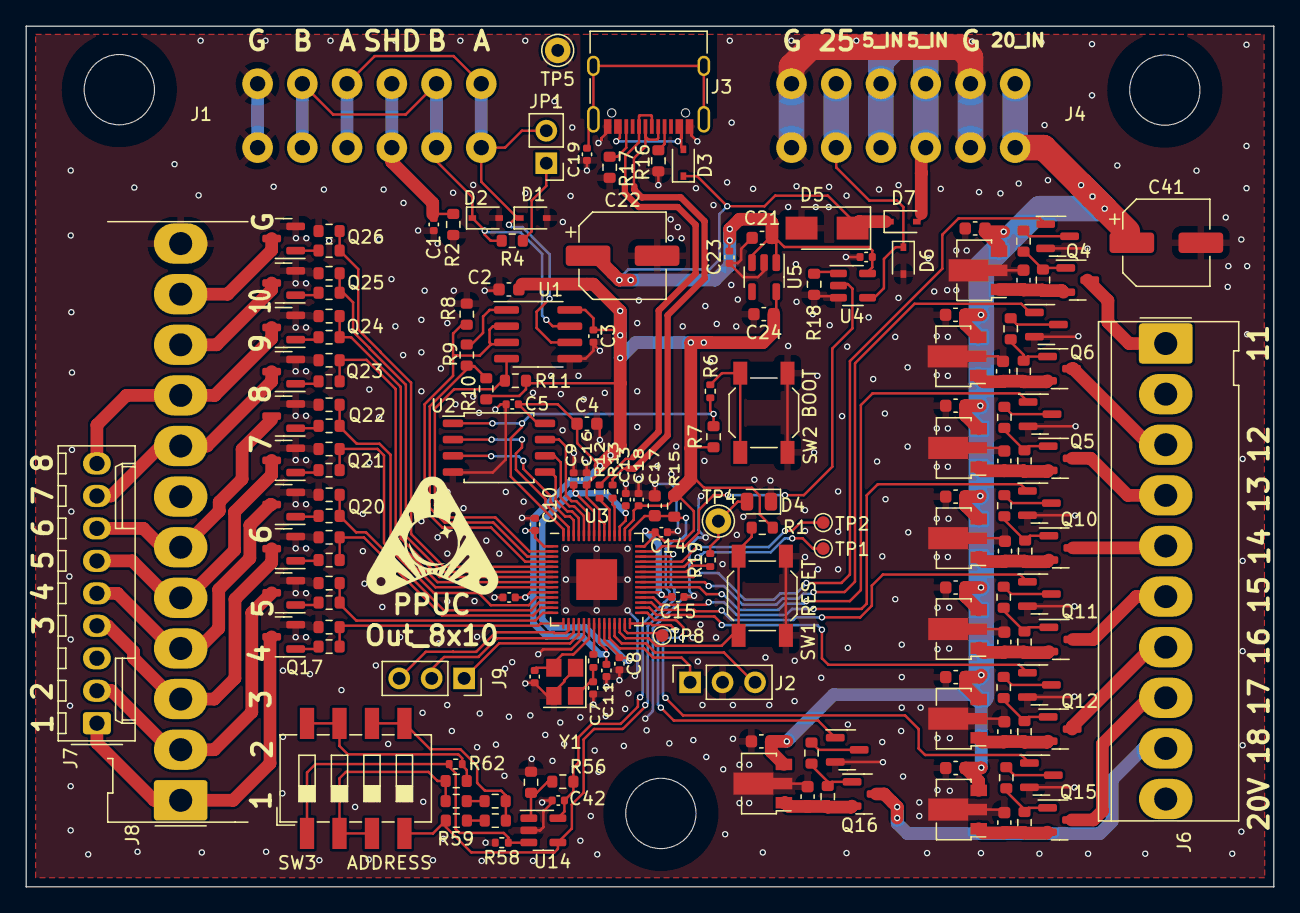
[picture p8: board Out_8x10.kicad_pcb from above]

Board: 2 copper layers, 97.6 x 67.3 mm, 169 parts (0 on the bottom side), 125 nets.

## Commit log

2023-10-11 updated layout
    [Hi8.kicad_sch, Lo10.kicad_sch, Out_8x10.kicad_pcb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]
2023-10-20 Analog DIP
    [Hi8.kicad_sch, Lo10.kicad_sch, Out_8x10.kicad_pcb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]
2023-10-20 schmaPDF updated
    [Hi8.kicad_sch, Lo10.kicad_sch, Out_8x10.kicad_sch]
2023-10-22 TPs to RM2.54
    [Hi8.kicad_sch, Lo10.kicad_sch, Out_8x10.kicad_pcb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]
2024-03-27 prod. data
    [Out_8x10-B_Cu.gbl, Out_8x10-B_Mask.gbs, Out_8x10-B_Paste.gbp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]
